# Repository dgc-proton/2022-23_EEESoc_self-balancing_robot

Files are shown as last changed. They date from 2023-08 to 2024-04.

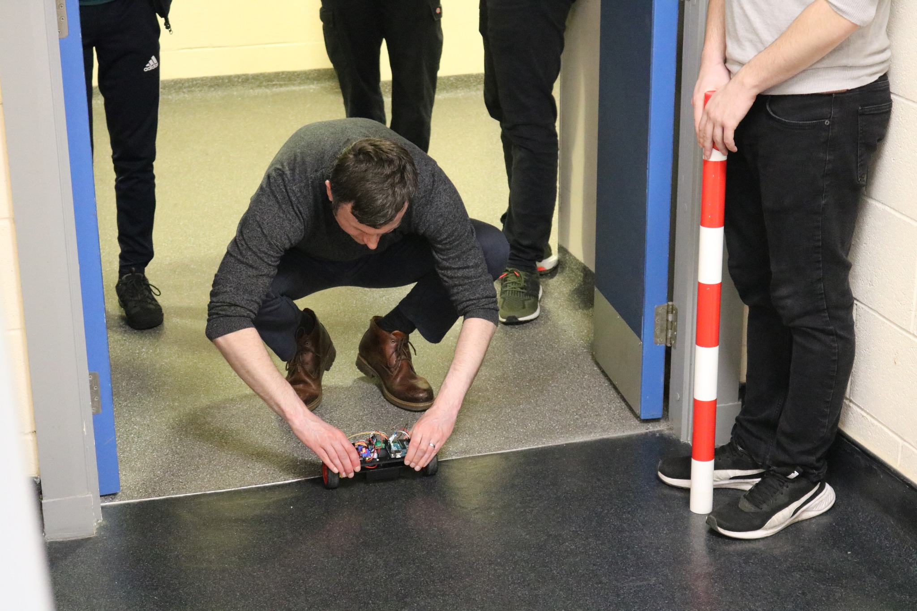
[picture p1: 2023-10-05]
competition_pic_3.jpg

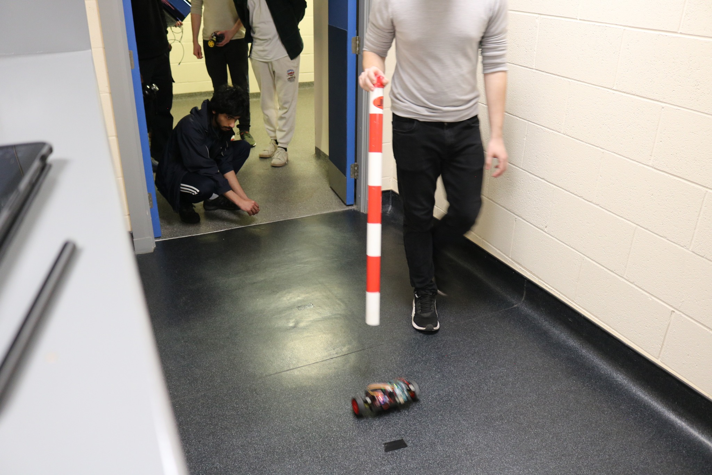
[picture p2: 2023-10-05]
competition_pic_2.jpg

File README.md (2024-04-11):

# Self Balancing Robot

This repository contains files relating to the final version of a self-balancing robot built by Dave & Anoop to enter the 2022-23 Aberdeen University Electrical & Electronic Engineering Society Robotics League; a self balancing robot competition. There are some pictures of the robot competing ([self-balancing for time](competition_pic_1.jpg), [hill-climbing with weight](competition_pic_2.jpg), [hill-climbing without weight](competition_pic_3.jpg)), the [robot chassis design](chasis.SLDPRT) in CAD (Solidworks), and the [source code](second_chassis_v3.1.ino) for the microcontroller.

The competition had 7 events which all competitors had to compete in:

- Self-balancing for time
- Self-balancing for time with added weight
- Maximum distance in a straight line
- Maximum distance in a straight line with added weight
- Maximum distance going up an incline
- Maximum distance going up an incline with added weight
- Robot wrestling (this was a suprise event that was revealed during the competition)

Overall our robot came in second place in the competition. It performed particularly well in the suprise wrestling round due to our remote control implementation.

# Parts List

The parts allowed were restricted to the below as part of the competition:

- 3D printed chassis
- Arduino Uno microcontroller unit (or clone)
- L298N motor driver
- MPU6050 based 3-axis gyroscope & accelerometer (6DOF) sensor
- TT motor x 2 (3-6V, gearing 1:48 plastic)
- Elegoo 7.4V lithium battery pack
- Elegoo IR remote control
- IR sensor
- wheels x 2

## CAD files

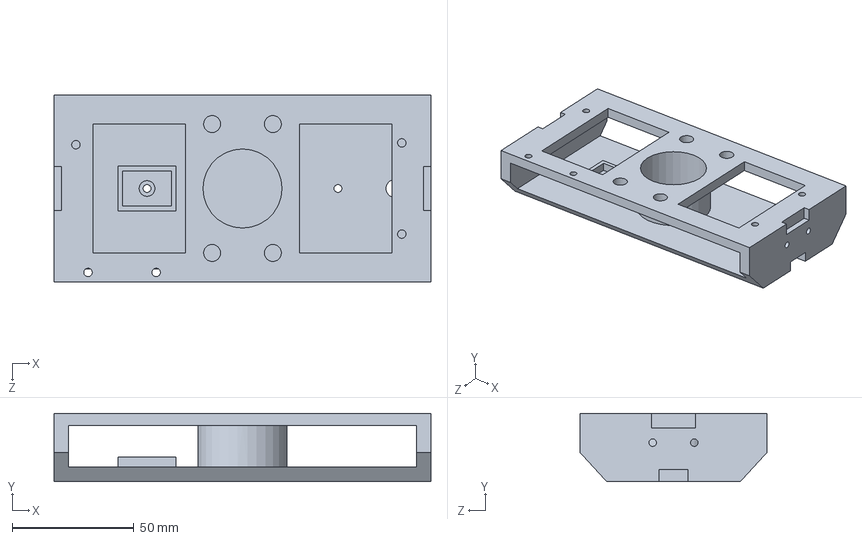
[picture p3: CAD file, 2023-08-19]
chasis.SLDPRT
155.0 x 28.0 x 77.0 mm

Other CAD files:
chasis.STL

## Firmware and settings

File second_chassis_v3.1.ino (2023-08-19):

/*
********************************************
*** Dave & Anoop Robot "second chassis"  ***
********************************************
*History:
*v1.0      23.03.23 Taking code across from "alt2" version one part at a time, testing and altering as necessary. Competition is next week.
*v1.5      24.03.23 Fixed bug where right wheel wouldn't move - turns out that the ISR was using the timer needed for all PWM pins past pin6.
*v2.0      24.03.23 Robot struggling to balance - wheels too agressive so changed how motor stall & motor speed are implemented, added coasting for motors,
*                   moved set_motor_speed to ISR. Robot can now balance close to indefinately on some ocassions.
*v2.5      25.03.22 Implementing IR control of robot - IRreceiver needs a hardware timer but all are in use, so changing to IRsmallDecoder library using interupt pin.
*                   Found further conflicts between IRsmallDecoder, and both the ISR and the MPU. Modified libraries to resolve.
*v2.6      25.03.23 Now making changes so that turning works better. Moved motot routine call back to main code loop.
*v2.7      26.03.23 Eliminated PID errorsum contrain, coast angle & all motorMin. Tested different MPU chips but all had similar (or worse) drift. Max drift on
*                   this chip ~0.7 deg. Changed PID so that Ki applies to whole sum; several sources site this as easier to manually tune.
*v2.8      28.03.23 Tidied up unused code. Modified wheels with rubber bands. Implemented 'window' (FIFO size 20) for errorSum to limit history. Reverted Ki & Kd calcs
*                   back to origional KJ style (keeping the adjustments made since v1.0 above, but reverting changes made prior to this).
*v3.0      28.03.23 Now balances very well (major contributors since v2.7 being PID algorithm changes & implementing an errorSum 'window', PID values: Kp 12.4, Ki 4.8
*                   Kd 0.05). Now improving PID, turning & forwards tuning. Added map() to compensate for motor  deadband, and a momentary forward lean ability.
*v3.1      29.03.23 Reverted PID back to seperate KpValue, KiValue and KdValue. Increased errorSum window size.
********************************
*
*Inbuilt LED will flash a couple of times quickly after power-on to indicate successful initialisation. If
*unsucessfull it will continually flash and the program will not run.
*ributing
*===> Don't forget to turn off debug statements when not in use! <===
*
*/


/*
***************************************
************  Tuning Area  ************
***************************************
*/
// PWM correction factors (to ensure mototrs run the same speed) - one should be 1, the other <1
#define LMOTOR_CORRECTION_FACTOR 0.78 // !Max value is to be 1
#define RMOTOR_CORRECTION_FACTOR 1.0 // !Max value is to be 1
// Motor stall value, used to adjust motor values accounting for deadband
#define MOTORMIN 60 //68
// Turning factor (needs to be > 1)
#define T_FACTOR 1.35
// Value to add to targetAngle for momentary forward lean
#define FORWARD_LEAN 0.22
// definitions for PID constants & sample time
#define Kp 16.0 //12.2 
#define Ki 12.5//12.5 //9.0 
#define Kd 0.68 //0.68 
#define sampleTime 0.005
//*************************************


// MPU
#define OFFSETS -1526,    1252,    1610,     226,       2,      34  // newer chip 1554,     996,    1926,      95,      11,      26 // older chip: -1526,    1252,    1610,     226,       2,      34
#define MPU6050_DEFAULT_ADDRESS 0x68
#define Three_Axis_Quaternions 3
#define Six_Axis_Quaternions 6  // Default

// left motor definitions
#define LMOTOR_PWM_PIN   3
#define LMOTOR_DIR_PIN_1 4 
#define LMOTOR_DIR_PIN_2 6
// right motor definitions
#define RMOTOR_DIR_PIN_1 7 
#define RMOTOR_DIR_PIN_2 8
#define RMOTOR_PWM_PIN   5

// IR receiver protocol
#define IR_SMALLD_NEC

// Header files & global object creation
#include <math.h>
#include <Arduino.h>
#include <DMP_Image.h>
#include <MPU_ReadMacros.h>
#include <MPU_WriteMacros.h>
#include <Simple_MPU6050.h> // Note: commented out line 35 to eliminate conflict with IRsmallDecoder (load this header file first)
Simple_MPU6050 mpu(Three_Axis_Quaternions); // Setup mpu object
#include <IRsmallDecoder.h> 
IRsmallDecoder irDecoder(2); // setup IR receiving object for pin 2 (needs to be a digital interrupt pin)

// Global variables
volatile float targetAngle = 1.22, prevAngle = 0.0, currentAngle = 0.0; // degrees (target 1.22)
volatile float KpValue, KiValue, KdValue;
volatile float error = 0.0, prevError = 0.0, errorSum = 0.0;
volatile float error_queue[40] = {0}; // for tracking the errorSum 'window' 
volatile int error_queue_counter = 0; // for tracking the errorSum 'window'
float euler[3];         // [psi, theta, phi]    Euler angle container
float eulerDEG[3];         // [psi, theta, phi]    Euler angle degrees container
volatile int motorPower;
static int motorDirection = 1, LmotorP = 0, RmotorP = 0;
static int powerValue = 0, forwardLean = 0;
static float LmotorTurn = 1, RmotorTurn = 1;
irSmallD_t irData; // for IRsmallDecoder

// Function prototypes
void init_interrupt(void);
void setup(void);
void init_MPU(void);
void setMotorSpeed(void);
void convert_readings(int16_t *gyro, int16_t *accel, int32_t *quat);
void read_ir(void);


/******************************
***  Setup code, runs once  ***
*******************************/
void setup() {  
  // Serials comms
  Serial.begin(9600);

  // Set motor pins as output
  pinMode(LMOTOR_DIR_PIN_1, OUTPUT);
  pinMode(LMOTOR_DIR_PIN_2, OUTPUT);
  pinMode(LMOTOR_PWM_PIN, OUTPUT); 
  pinMode(RMOTOR_DIR_PIN_1, OUTPUT);
  pinMode(RMOTOR_DIR_PIN_2, OUTPUT);
  pinMode(RMOTOR_PWM_PIN, OUTPUT); 

  // set inbuilt LED pin (D13) as output to show when MPU initialised
  pinMode(LED_BUILTIN, OUTPUT);

  // Initialise MPU6050 inc DMP
  init_MPU();

  // set motors in forward direction
  digitalWrite(LMOTOR_DIR_PIN_1, LOW);
  digitalWrite(LMOTOR_DIR_PIN_2, HIGH);
  digitalWrite(RMOTOR_DIR_PIN_1, LOW);
  digitalWrite(RMOTOR_DIR_PIN_2, HIGH);

  // Setup ISR
  init_interrupt();  

  // blink LED to show completed
  digitalWrite(LED_BUILTIN, HIGH);
  delay(100);
  digitalWrite(LED_BUILTIN, LOW);
  delay(100);
  digitalWrite(LED_BUILTIN, HIGH);
  delay(100);
  digitalWrite(LED_BUILTIN, LOW);
}


/***********************************
***  Main code, runs repeatedly  ***
***********************************/
void loop() {
  // Get readings from mpu DMP; function will poll data then call convert_readings routine  
  mpu.dmp_read_fifo(false);
  // Motor routine 
  setMotorSpeed(); 

  // Cancel any forward lean, then check if any IR commands have been received and action them.
  // Only done once per loop because less time critical.
  if (forwardLean) {
    forwardLean = 0;
    targetAngle -= FORWARD_LEAN;
  }
  read_ir();
  // Add any forward lean
  if (forwardLean) {
    targetAngle += FORWARD_LEAN;
  }

  // DEBUGGING  (for use with Python serial reading & plotting script)
  //Serial.println(String(millis()) + "," + String(currentAngle) + "," + String(prevAngle) + "," + String(error) + "," + String(errorSum)
  //               + "," + String(KpValue) + "," + String(KiValue) + "," + String(KdValue) + "," + String(powerValue));
}


/****************************************
***  Control motor speed & direction  ***
****************************************/
void setMotorSpeed(void)
{
  // Set motor direction according to current and target angles
  if (currentAngle > targetAngle && motorDirection != 1)
  {
    // set motors in forward direction
    digitalWrite(LMOTOR_DIR_PIN_1, LOW);
    digitalWrite(LMOTOR_DIR_PIN_2, HIGH);
    digitalWrite(RMOTOR_DIR_PIN_1, LOW);
    digitalWrite(RMOTOR_DIR_PIN_2, HIGH);
    motorDirection = 1;
  }
  else if (currentAngle < targetAngle && motorDirection != 0)
  {
    // set motors in the reverse direction
      digitalWrite(LMOTOR_DIR_PIN_1, HIGH);
      digitalWrite(LMOTOR_DIR_PIN_2, LOW);  
      digitalWrite(RMOTOR_DIR_PIN_1, HIGH);
      digitalWrite(RMOTOR_DIR_PIN_2, LOW);
      motorDirection = 0;          
  }  

  // Set powervalue
  powerValue = (abs(motorPower));
  powerValue = constrain(powerValue, 0, 170); // constrained to 170 to allow for motor turning factor of upto 50%
  powerValue = map(powerValue, 0, 170, MOTORMIN, 170); // adjust to account for motor stall value
  // If robot falling over cut power to motors
  if (abs(currentAngle) > 50) {
    powerValue = 0;
  }
  LmotorP = ceil((powerValue) * LMOTOR_CORRECTION_FACTOR);
  RmotorP = ceil((powerValue) * RMOTOR_CORRECTION_FACTOR);
  
  // Update powervalue output to motors
  if (motorDirection == 1) {
    analogWrite(LMOTOR_PWM_PIN, ceil(LmotorP * LmotorTurn));
    analogWrite(RMOTOR_PWM_PIN, ceil(RmotorP * RmotorTurn));
  } else {
    analogWrite(LMOTOR_PWM_PIN, LmotorP);
    analogWrite(RMOTOR_PWM_PIN, RmotorP);
  }  
}


/**********************************************************
***  Interrupt Service Routine - calculates motorPower  ***
**********************************************************/
ISR(TIMER1_COMPA_vect)
{
    prevAngle = currentAngle;
    prevError = error; 
    currentAngle = (float) eulerDEG[2];
    
    // calculate error for a window of 40 readings
    error = currentAngle - targetAngle;
    errorSum += error;
    errorSum -= error_queue[error_queue_counter];
    error_queue[error_queue_counter] = error;
    error_queue_counter += 1;
    if (error_queue_counter > 39){
        error_queue_counter = 0;
    }

    //calculate output from Kp, Ki and Kd values
    KpValue = Kp * error;
    KiValue = Ki * errorSum * sampleTime;
    KdValue = Kd * ((currentAngle - prevAngle) / sampleTime);
    motorPower = (KpValue + KiValue + KdValue);
}

/************************************************************************************************
***  Check if IR sensor data available and carry out instructions if they have been received  ***
************************************************************************************************/
void read_ir(void)
{
  // Carry out jobs only if command has been received
  if (irDecoder.dataAvailable(irData)) {
    // Perform actions according to the received command
    if (irData.cmd == 0x46) {
        //Serial.println("up");
        targetAngle += 0.05;        
    } else if (irData.cmd == 0x15) {
        //Serial.println("down");
        targetAngle -= 0.05;        
    } else if (irData.cmd == 0x40) {
        //Serial.println("ok");
        LmotorTurn = 1.0;
        RmotorTurn = 1.0;
    } else if (irData.cmd == 0x44) {
        //Serial.println("left");
        LmotorTurn = 1.0;
        RmotorTurn = T_FACTOR; // Right motor turns faster when going forwards
    } else if (irData.cmd == 0x43) {
        //Serial.println("right");
        RmotorTurn = 1.0;
        LmotorTurn = T_FACTOR; // Left motor turns faster when going forwards
    } else if (irData.cmd == 0x19) {
        //Serial.println("2");
        targetAngle = 0.0;
    } else if (irData.cmd == 0x16) {
        //Serial.println("1");
        forwardLean = 1;
    }
  }
}


/********************************************
***  Convert DMP readings to usable data  ***
********************************************/
void convert_readings(int16_t *gyro, int16_t *accel, int32_t *quat)
{
    Quaternion q;
    VectorFloat gravity;
    float ypr[3] = { 0, 0, 0 };
    mpu.GetQuaternion(&q, quat);  
    mpu.GetGravity(&gravity, &q);
    mpu.GetEuler(euler, &q);
    mpu.ConvertToDegrees(euler, eulerDEG);
}


/******************
***  Setup ISR  ***
******************/
void init_interrupt(void)
{
    cli();                      // disable global interrupts
    TCCR1A = 0;                 // set entire TCCR1A register to 0
    TCCR1B = 0;                 // same for TCCR1B  
    OCR1A = 9999;               // set timer for 5ms
    TCCR1B |= (1 << WGM12);     // turn on CTC mode
    TCCR1B |= (1 << CS11);      // Set CS11 bit for prescaling by 8
    TIMSK1 |= (1 << OCIE1A);    // enable timer compare interrupt
    sei();                      // enable global interrupts
}


/************************
***  Setup MPU & DMP  ***
************************/
void init_MPU(void)
{
    mpu.begin();
    mpu.Set_DMP_Output_Rate_Hz(200);
    mpu.SetAddress(MPU6050_DEFAULT_ADDRESS); 
    mpu.setOffset(OFFSETS);
    mpu.CalibrateGyro();
    mpu.CalibrateAccel();
    mpu.load_DMP_Image();
    mpu.on_FIFO(convert_readings);
}

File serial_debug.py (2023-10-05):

import serial
from sys import exit
from time import sleep
import numpy as np
import pandas as pd
import matplotlib.pyplot as plt

def main():
    ser = serial.Serial("/dev/ttyACM0", 9600)
    print(f"Details of connection: \n{ser}")
    print(f"Connection open: {ser.is_open} \n\n")
    ser.flushInput
    data = bytes()

    print("**Capturing data**")
    data = capture_data()
    
    print("\nClosing connection")
    ser.close()
    print(f"Connection open: {ser.is_open}")
    print("Converting and saving data")

    # Add headings to the data
    headings = "Time_(ms), Angle_(rad), Prev_Angle, Error, Error_Sum, Kp, Ki, Kd, Power_Value\n"
    for i, byte in enumerate(bytearray(headings, "ascii")):
        data.insert(i, byte)

    with open("serial_output.csv", "wb") as file:
        file.write(bytearray(data))

    # plot graph
    data_to_graph("serial_output.csv")

    

def capture_data():
    data = bytearray()
    with serial.Serial("/dev/ttyACM0", 9600) as ser:
        while True:
            try:
                data += ser.read()
            except KeyboardInterrupt:
                break
    # process the data    
    counter = 0
    last_nl_position = 0 
    for i, byte in enumerate(data):
        # remove any bytes that are not deemed valid output from the microcontroller
        if not (0 <= int(byte) <= 127):
            del data[i]
        # remove the initial messy data
        if (int(byte) == 10):     # and data[i+1] == "r" and data[i+2] == "\\" and data[i+3] == "n"
            counter += 1
            last_nl_position = i
            if counter == 50:
                del data[:i+5]
    # delete after the last newline to eliminate incomplete data
    del data[last_nl_position:]   
    return data


def data_to_graph(filename):
    #import excel data into its own data frame
    df_xls = pd.read_csv (filename, sep=",", header=0, index_col=False, engine='python', skipinitialspace=True) 
    print(df_xls.columns)
    # plot graph
    plt.rcParams.update({'font.size': 22})
    fig, axs = plt.subplots(1, layout="constrained")
    axs.plot(df_xls["Time_(ms)"], df_xls["Error"], linewidth=1, color="b", label="Error")
    axs.plot(df_xls["Time_(ms)"], (df_xls["Angle_(rad)"] ), linewidth=1, color="g", label="Angle")
    axs.plot(df_xls["Time_(ms)"], df_xls["Error_Sum"], linewidth=1, color="r", label="Error Sum")
    axs.plot(df_xls["Time_(ms)"], df_xls["Kp"], linewidth=1, color="c", label="Kp")
    axs.plot(df_xls["Time_(ms)"], df_xls["Ki"], linewidth=1, color="m", label="Ki")
    axs.plot(df_xls["Time_(ms)"], df_xls["Kd"], linewidth=1, color="k", label="Kd")
    axs.plot(df_xls["Time_(ms)"], (df_xls["Power_Value"]), linewidth=1, color="y", label="Power Value")
    axs.set_xlabel("Time", fontweight="bold")
    axs.set_ylabel("", fontweight="bold")
    #axs.set_ylim(0) 
    #axs.set_xlim(0)
    axs.legend()
    plt.show()

if __name__ == "__main__":
    main()


"""
    data = ser.read(size=1000)

    ser.close()
    print(f"Connection open: {ser.is_open}")

    if data:
        print("Data is now being written to file")
        try:
            decoded = str(data)
        except:
            exit("Some sort of exception occurred while converting the data")
        try:
            with open("serial_output.csv", "w") as file:
                file.write(decoded)
        except:
            exit("Some sort of exception occurred while writing file")
        print("Data written to file successfully")
    else:
        print("No data was read")


    """


"""
try:
        while True:
            data += ser.readline()
    except KeyboardInterrupt:
        ser.close()
        print(f"\nConnection open: {ser.is_open}")
        if (len(data) > 100):
            print("Data is now being written to file")
            try:
                str_data = str(data.decode("utf-8", "ignore"))
            except:
                exit("Some sort of exception occurred while converting the data to string")
            
            # Decode the data
            decoded = str()
            counter = 0
            # remove the leading 2 characters
            for i, letter in enumerate(str_data):
                if (letter == "\\" and str_data[i+1] == "r" and str_data[i+2] == "\\" and str_data[i+3] == "n"):
                    counter += 1
                    if counter == 10:
                        clipped_data = str_data[i+5:]
                        break
            # insert the newline characters
            if clipped_data:
                clipped_data.replace(r"\\r\\n", "\n")
            else:
                exit("Error: data was not decoded successfully")

            # save the data
            try:
                with open("serial_output.csv", "w") as file:
                    file.write(clipped_data)
            except:
                exit("Some sort of exception occurred while writing file")
            print("Data written to file successfully")
        else:
            print("No, or insufficient, data was read! Try re-plugging in the usb cable to Arduino.")
            exit()
    """

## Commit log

2023-08-19 Initial upload of files (competition versions)
    [chasis.SLDPRT, chasis.STL]
2023-10-05 Added serial debugger and motor stall test files
    [serial_debug.py, sketch_test_motor_stall_PWM.ino]
